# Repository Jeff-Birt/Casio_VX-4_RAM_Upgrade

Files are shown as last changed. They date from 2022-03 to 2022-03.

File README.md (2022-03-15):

# Casio_VX-4_RAM_Upgrade
NOTE: I would not reccomend making PCBs form the current posted version. I found the zebra strip contact
pads were about 0.5mm too far from end to end. This was the result of an odd problem with Eagle where
it was reading from a 'part.lbr. file in the project directory when editing the footprint but from the
component library when gnerating the PCB. I have fixed the PCB and have some new ones ordered. I will
upload the new PCB version after I'm able to build and test a few boards.

Internal and external RAM upgrades for Casio VX-4 and similar models. RP-33 clone.

The RP-33 works in the following Casio models: RP-33 works with: FX-840P, FX-841P, FX-850P, FX-860P, 
FX-860Pvc, FX-870P, FX-880P, FX-890P, VX-1, VX-2, VX-3, VX-4, Z-1, Z-1GR, PB2000C and AI-1000

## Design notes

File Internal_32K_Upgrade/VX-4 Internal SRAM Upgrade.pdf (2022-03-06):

## CASIO VX-4 8K to 32K Internal SRAM upgrade

Images from: https://icelord.net/wordpress/archives/17133

Original 8K:

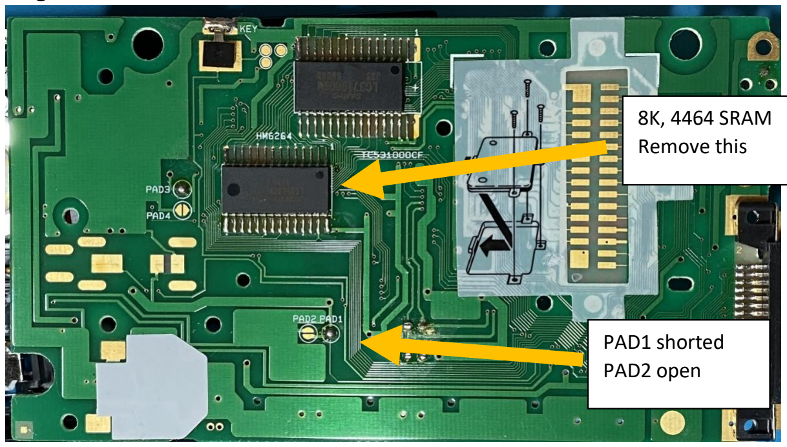
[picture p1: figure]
PAD1 shorted PAD2 open; 8K, 4464 SRAM Remove this

32K upgrade:

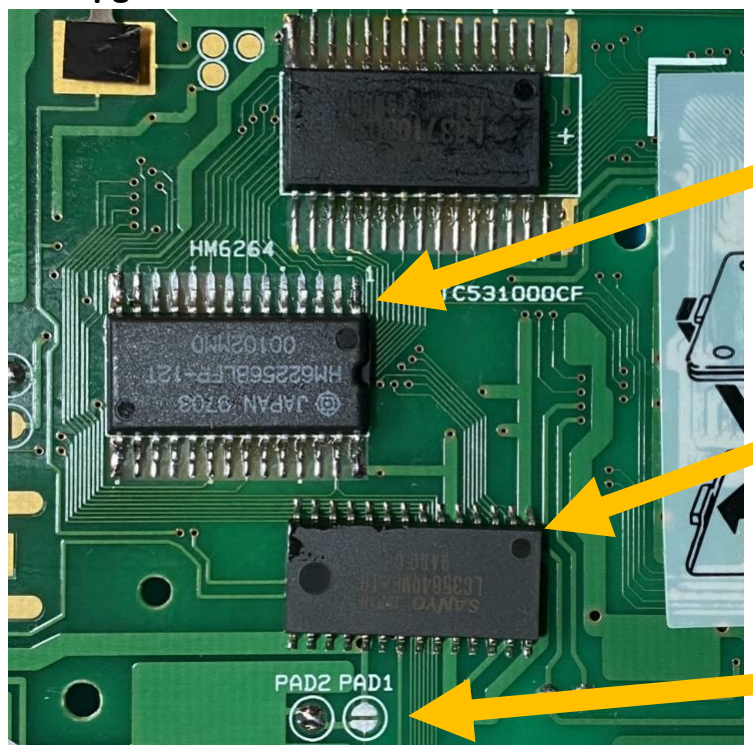
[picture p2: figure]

After swap: Install batteries, press reset button (through hole) on back, press ‘All Reset’ (through hole) on keyboard. Type in: SYSTEM* then hit EXE. Run RAM tests 4, 5, 6. If no errors returned your upgrade is OK.

PAD1 open
PAD 2 shorted

32K
HM62256BLFP Low Power
SRAM (or similar). Replaces original SRAM. Arrow
pointing to Pin 1 location.

Old 8K SRAM shown for
comparison. Not needed,
remove completely.

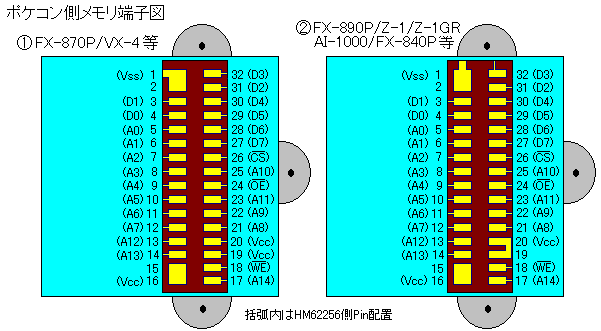
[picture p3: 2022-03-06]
RP_33_Redux/Manual_and_Information/Connector_Pad_Pinout_Japanse.png

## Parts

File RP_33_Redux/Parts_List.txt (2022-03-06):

Name	Qty	Part#				Notes
PCB1 	1 	RP-33 redux PCB 					
IC1  	1 	KM62256CLTG-7L			Forward pinout, low power
C1   	1 	0.1uf 0603 capacitor
SCRW1	3	1.7mmx0.35x3 pan head screw	4mm length OK too
SHM1	1	3D printed shim

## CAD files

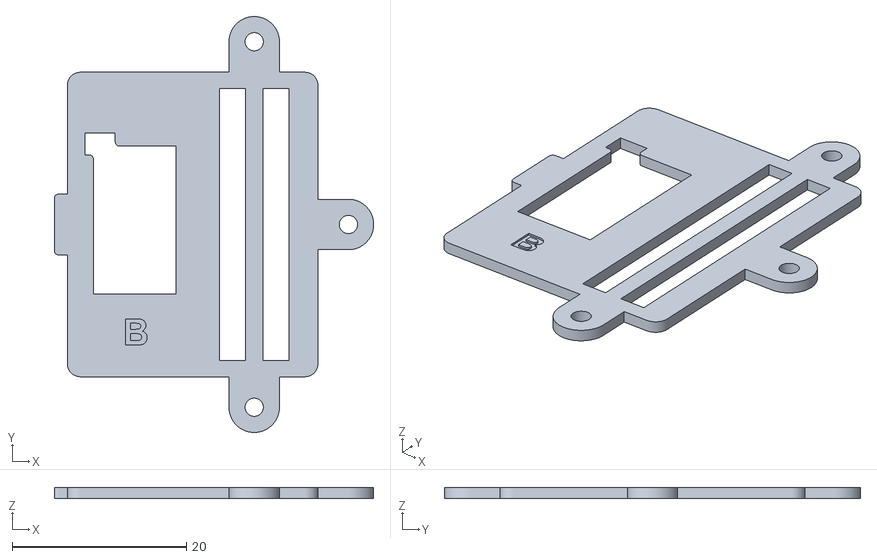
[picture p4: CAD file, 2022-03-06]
RP_33_Redux/3D Print Files/Alignment_Plate_Split_32.stl
36.7 x 47.8 x 1.25

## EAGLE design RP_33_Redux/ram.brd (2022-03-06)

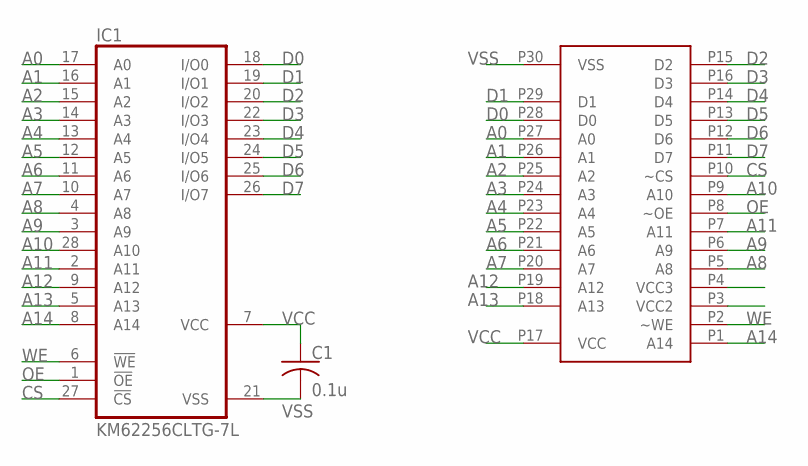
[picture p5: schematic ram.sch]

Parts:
C1: 0.1u; C0603
IC1: KM62256CLTG-7L; TSOP1-28
U$1: RAMPORT; CASIORAM

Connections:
A0: IC1.17 (A0), U$1.P27 (A0)
A1: IC1.16 (A1), U$1.P26 (A1)
A2: IC1.15 (A2), U$1.P25 (A2)
A3: IC1.14 (A3), U$1.P24 (A3)
A4: IC1.13 (A4), U$1.P23 (A4)
A5: IC1.12 (A5), U$1.P22 (A5)
A6: IC1.11 (A6), U$1.P21 (A6)
A7: IC1.10 (A7), U$1.P20 (A7)
A8: IC1.4 (A8), U$1.P5 (A8)
A9: IC1.3 (A9), U$1.P6 (A9)
A10: IC1.28 (A10), U$1.P9 (A10)
A11: IC1.2 (A11), U$1.P7 (A11)
A12: IC1.9 (A12), U$1.P19 (A12)
A13: IC1.5 (A13), U$1.P18 (A13)
A14: IC1.8 (A14), U$1.P1 (A14)
CS: IC1.27 (!CS), U$1.P10 (~CS)
D0: IC1.18 (I/O0), U$1.P28 (D0)
D1: IC1.19 (I/O1), U$1.P29 (D1)
D2: IC1.20 (I/O2), U$1.P15 (D2)
D3: IC1.22 (I/O3), U$1.P16 (D3)
D4: IC1.23 (I/O4), U$1.P14 (D4)
D5: IC1.24 (I/O5), U$1.P13 (D5)
D6: IC1.25 (I/O6), U$1.P12 (D6)
D7: IC1.26 (I/O7), U$1.P11 (D7)
OE: IC1.1 (!OE), U$1.P8 (~OE)
VCC: C1.1, IC1.7 (VCC), U$1.P17 (VCC)
VSS: C1.2, IC1.21 (VSS), U$1.P30 (VSS)
WE: IC1.6 (!WE), U$1.P2 (~WE)

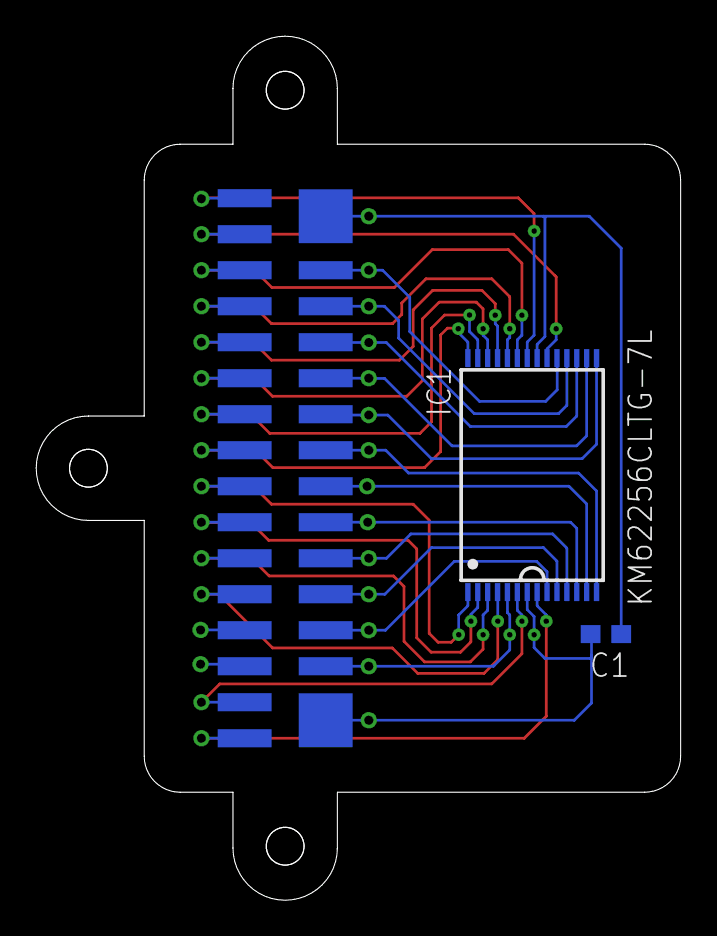
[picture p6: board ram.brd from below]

Board: 2 copper layers, 35.8 x 48.0 mm, 3 parts (2 on the bottom side), 28 nets.

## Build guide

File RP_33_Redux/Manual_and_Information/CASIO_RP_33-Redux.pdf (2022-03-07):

# Soigeneris

RP-33

# Hey Birt! Casio RP-33 Replacement

### User’s Manual V1.0

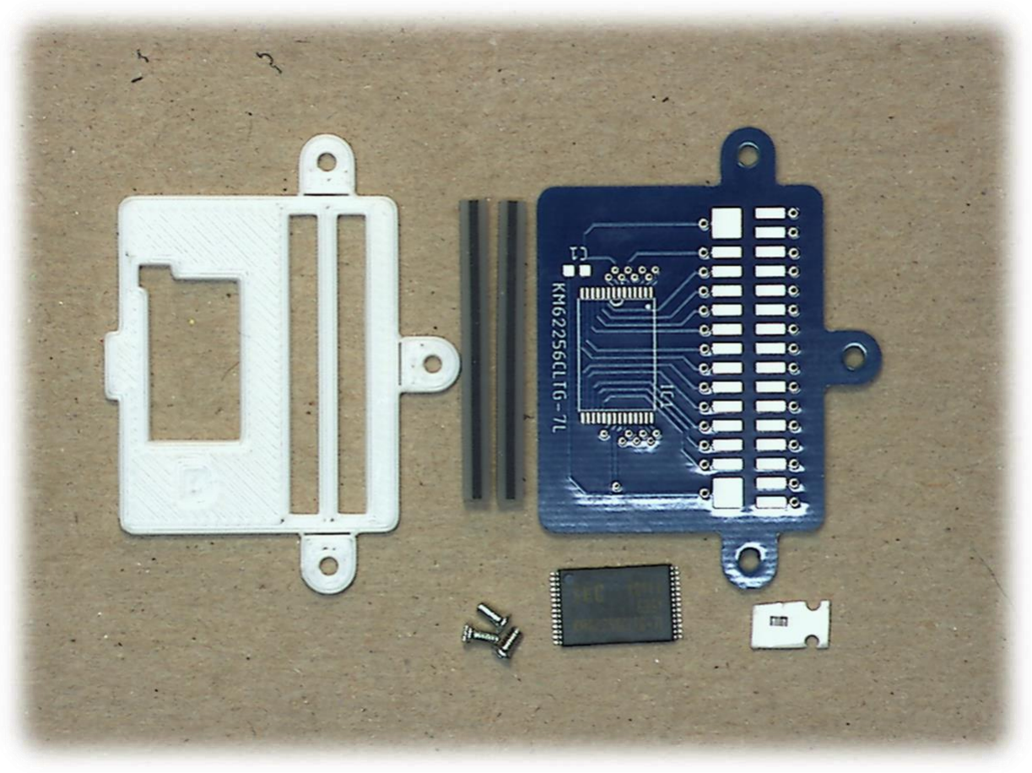
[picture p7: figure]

Page 2

304 Fox Creek Road
Rolla, MO 65401 US
573-647-9294

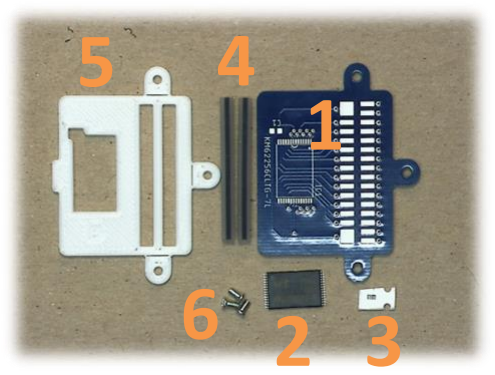
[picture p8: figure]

What’s Included in Kit

1) PCB
2) KM62256CLTG-7L, low power, TSOP SRAM
3) 0.1uf cap, 0603 pkg
4) Zebra strip, 31mm x 3 x 2.8, 2 pcs
5) 3D Printed Shim
6) Pan head screw, 1.7mm x 0.35 x 3, 3 pcs

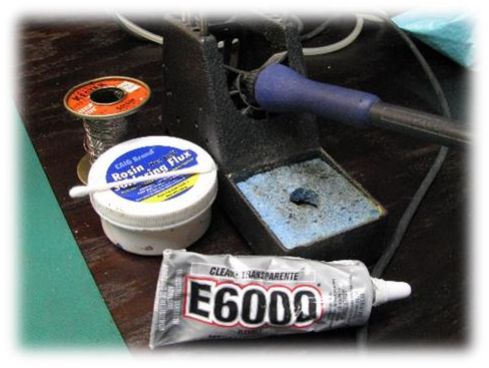
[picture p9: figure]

What you need

1) Soldering iron
2) Solder
3) Flux
4) E6000 glue (or similar)
5) #46 (2mm) drill bit, 3 pcs (or similar)
6) A magnifier helps a lot too

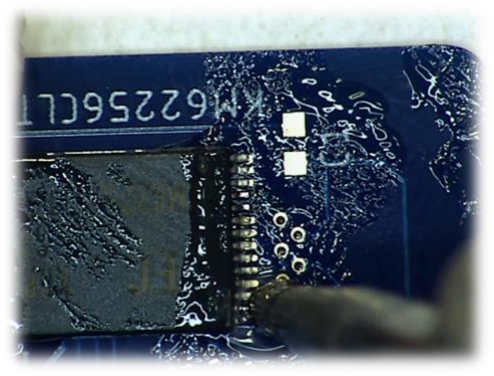
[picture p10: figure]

Directions

1) Solder SRAM chip onto the PCB taking care not to get any solder onto the Zebra strip contact pads. Use Kapton tap to protect the pads. Note the Pin 1 marking on PCB and on the SRAM chip. Make sure to orient the chip correctly.

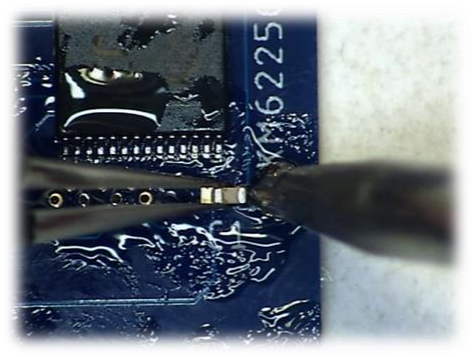
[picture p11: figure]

2) Solder on the capacitor. This is a not a polarized part so orientation does not matter.

Page 3

Rolla, MO 65401 US
573-647-9294

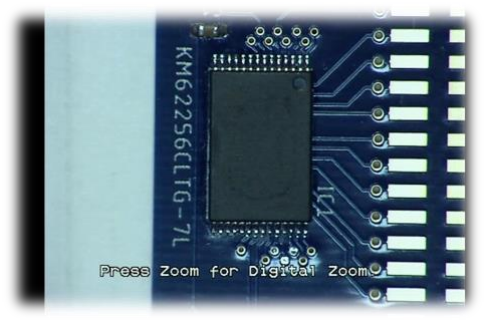
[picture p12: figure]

3) Clean the PCB very thoroughly with alcohol and flux/PCB cleaner. The PCB must be Perfectly clean before gluing the shim in place. Let the board dry for a least a few hours.

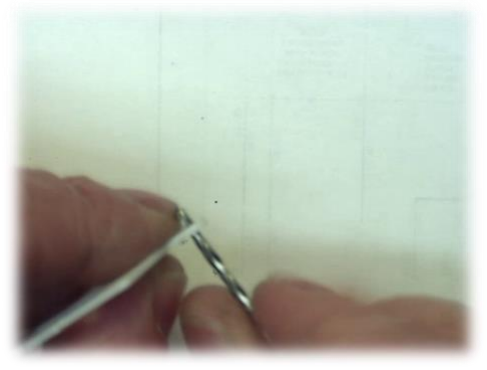
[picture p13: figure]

4) Carefully run your #39 drill bit through each hole in the shim until the bit slides through easily. We will use the bits to align the shim to the PCB.

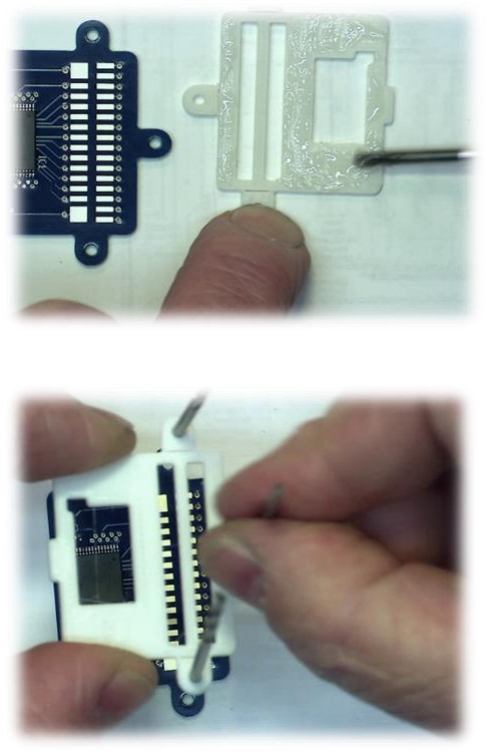
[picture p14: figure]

5) Sparingly apply the E600 glue. We want enough to hold the shim on but not enough to ooze out from under shim. Do not apply glue to the center bar separating the Zebra strips.
6) Slip the drill bits about 8mm though the shim. Insert the bits through the PCB holes and slowly slide the shim down and press it onto PCB with moderate force. Let it set 24 hours for glue to cure.

Page 4

Rolla, MO 65401 US
573-647-9294

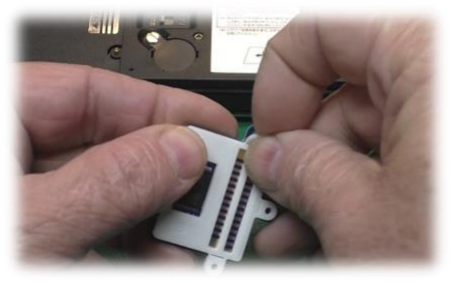
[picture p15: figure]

7) Remove drill bits and snap off alignment tabs on shim.

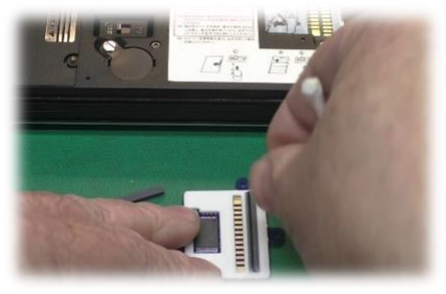
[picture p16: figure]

8) Wipe the Zebra strips with alcohol and then install them.

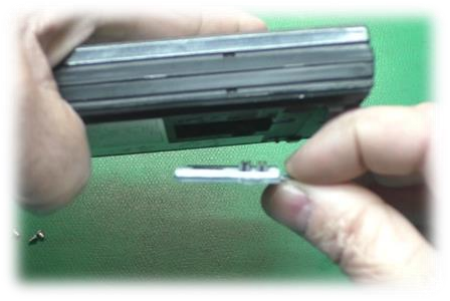
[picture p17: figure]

9) Hold VX-4 upside down at angle and place RP-33 up into hold slipping the foot on the shim into place. After the RP-33 has been installed for a while the Zebra strips will stay in place on the RPO-33 if you remove it.

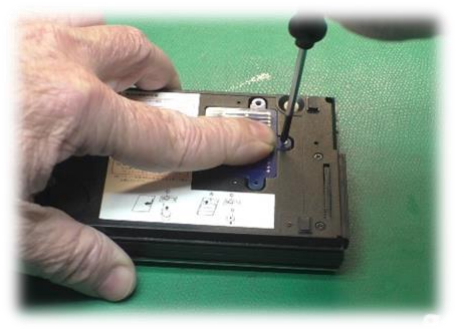
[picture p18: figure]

10) Press the RP-33 down and install the screws loosely at first and then snug them all down.

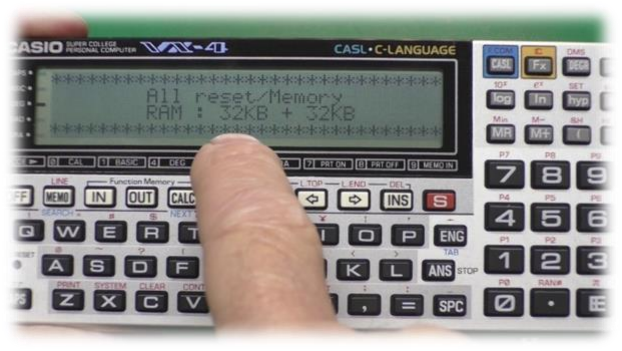
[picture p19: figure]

11) Enjoy using the RP-33 you just built! Instructions for resetting and testing below.

Page 5

Rolla, MO 65401 US
573-647-9294

How to reset rest the VX-4 and test the new RAM

Install the AA batteries, install the memory backup battery. Turn the power switch on the back to ON. Use a paperclip, etc. to push the master reset button through the hole in back. Then use the paperclip to press the ‘All Reset’ button through hole in keyboard.

The screen should now be flashing the RAM amount discovered on power up: 8K + 32K if you have not done the internal memory upgrade, or 32K + 32K if you have done the internal memory upgrade as well. If you see this your RP-33 was recognized. If not turn off the switch on the back and double check your RP-33.

To test the RAM type in SYSTEM* and press EXE. This will bring up a hidden test menu. Items 4, 5, 6 are the RAM tests. Press 4, then any key. This test will take 30 seconds or so to run. If it does not return an error message and goes back to the menu your RP-33 passed the test. Do the same with test 5 and 6.

After doing a RAM test you must press the ‘All Reset’ from the keyboard side before trying to use the unit. The RAM test writes to every location in RAM which confuses the BASIC editor, etc. Pressing ‘All Reset’ will initialize the system.

The RP-33 works with: FX-840P, FX-841P, FX-850P, FX-860P, FX-860Pvc, FX-870P, FX-880P, FX-890P, VX-1, VX-2, VX-3, VX-4, Z-1, Z-1GR, PB2000C and AI-1000

A video detailing the design and building of the MOS8701/HB can be found on YouTube at: https://youtu.be/DSXBF3-MclE

This is an open-source project created by Jeffrey T. Birt, a.k.a. ‘Hey Birt!’ Project files can be downloaded from the link below.

Github repository: https://github.com/Jeff-Birt/Casio_VX-4_RAM_Upgrade
